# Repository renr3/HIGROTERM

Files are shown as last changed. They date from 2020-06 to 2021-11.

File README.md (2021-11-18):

# HIGROTERM
This is the official repository of the open-source HIGROTERM system for laboratory monitoring of temperature and humidity.

Any scientific publications regarding HIGROTERM will be also made available here, whether in full text or reference links.

If you find HIGROTERM useful for your scientific work, or if you have used HIGROTERM in some way, consider citing the the following references:

  1. R. Rocha Ribeiro, E. Bauer, and R. Lameiras, “HIGROTERM: An Open-Source and Low-Cost Temperature and Humidity Monitoring System for Laboratory Applications”, <em>Inventions</em>, vol. 6, no. 4, p. 84, Nov. 2021. https://doi.org/10.3390/inventions6040084 
  2. **HIGROTERM repository on GitHub**: Rocha Ribeiro, R. (2021). renr3/HIGROTERM: First release (v0.1). Zenodo. https://doi.org/10.5281/zenodo.5525381 

The HIGROTERM system is an open-source temperature and humidity system developed at the Laboratory of Material Testing at the Department of Civil and Environmental Engineering of the University of Brasília.

In order to use the source code in your hardware, please access the "Source Code" folder and access the "A000_SourceCode_HIGROTERM_EnPtVersion_v0_4_DUE_Version", in which all the source .ino files are available, as well as two C files containing icon and fonts definition. The files in the "Documentation" folder will help you to understand the source code structure and to install the necessary libraries to upload the sketch in your Arduino.

The schematics for the PCB required to build and run the current version of HIGROTERM are dhown in the "Schematics" folder. The paper “HIGROTERM: An Open-Source and Low-Cost Temperature and Humidity Monitoring System for Laboratory Applications” thoroughly explains how to build a breadboard version, the Bill of Materials and other information required to replicate the system's hardware.

The HIGROTERM source code itself is licensed under the MIT license. However, the source code makes use of external libraries developed by third parties that are licensed under a myriad of different licenses. Please, make sure you consult the Documentations folder, in which the PDF file "ABOUT THE LIBRARIES" contains links to each library, as well as their current licenses (11, June 2020), in order to check if the use you intend for the HIGROTERM system complies with all the licenses involved.

Finally, for further guidance regarding the source code and libraries, please refer to the Documentation folder, into which you will find a PDF file "ABOUT THE SOURCE CODE" with a brief explanation about the source code structure, and the libraries used by the HIGROTERM source code, as well as the links to download them and the license under which they are released, in the PDF file "ABOUT THE LIBRARIES".

Hope you enjoy the project.

Best regards,

Renan Rocha Ribeiro

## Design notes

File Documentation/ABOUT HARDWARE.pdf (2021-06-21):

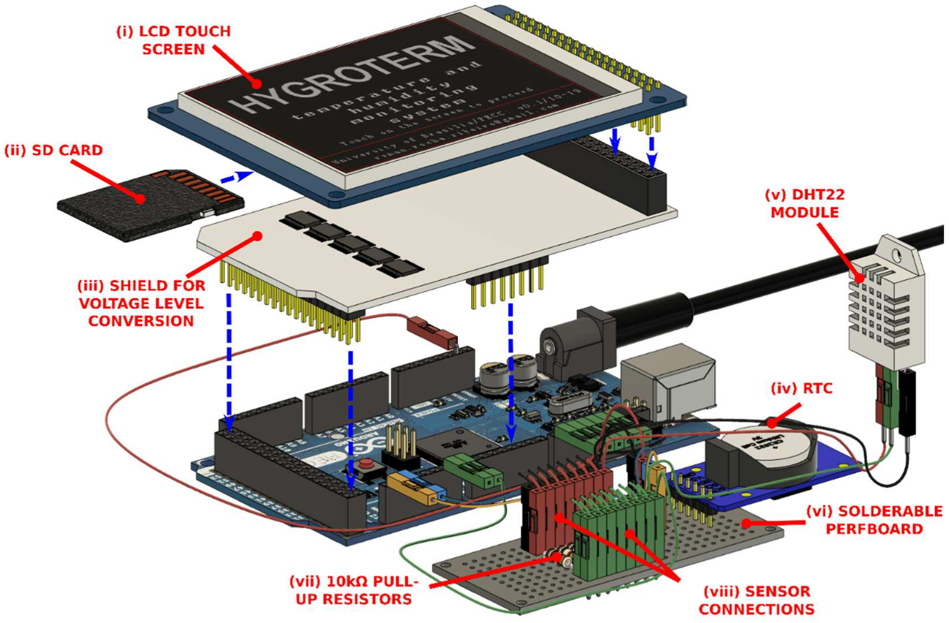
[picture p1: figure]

1

ABOUT HARDWARE USED

Renan Rocha Ribeiro

20, june of 2021

The HIGROTERM system is based upon the Arduino Mega board, DHT22 humidity and

temperature sensors, solderless breadboard and necessary cables and connectors. The full

description of the system will be part of a scientific published paper soon. In this document, a

brief explanation of the hardware necessary to build the HIGROTERM system is given.

An overall view of the system is shown in Figure 1 and how to easily assemble it in a perfboard

style.

Figure 1 Overall view of the hardware.

Figure 2 shows in more details the cable connection, without including the LCD screen and shield

for voltage level conversion, as they are directly stacked upon the Arduino Mega board. The

pinout connection shown is the same as used in the source code of the system. For better clarity,

the example only includes two units of DHT22 sensor, although the data lines for the 8 channels

are available and illustrated, although not connected to sensors.

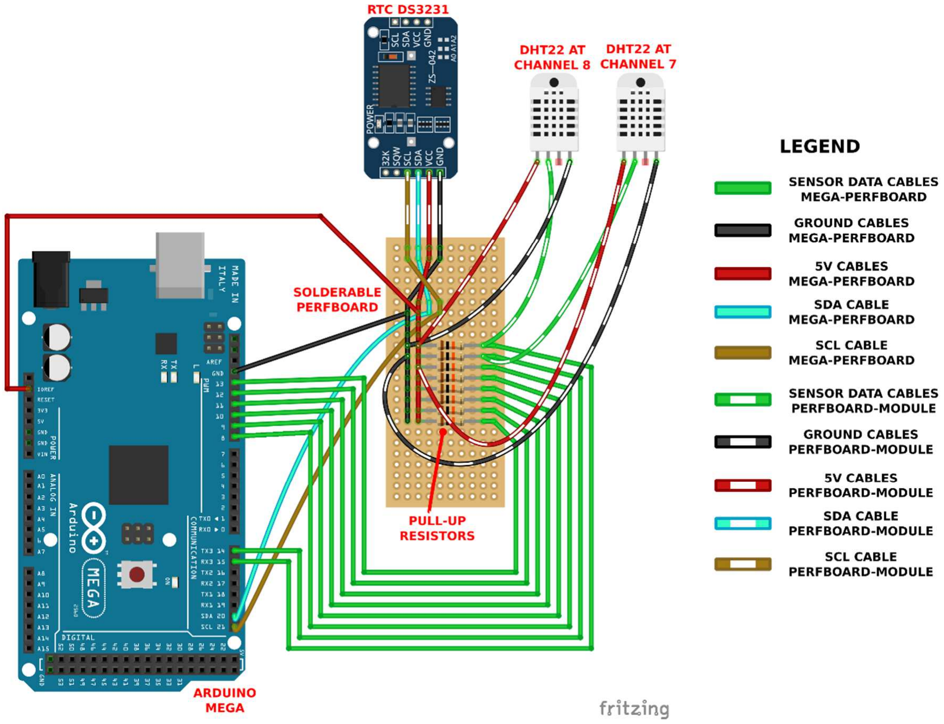
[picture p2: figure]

2

Figure 2 Cable connection using perfboard.

Figure 3 shows in more detail the cable connection using a breadboard. The shield for voltage

level conversion is shown for completeness’ sake, but its connection is to be done in a stacked

form. In Figure 3, 2EDG connectors, shown in green, are included to better reflect a suggestion

of a more reliable and flexible way to build the system and connect the sensors.

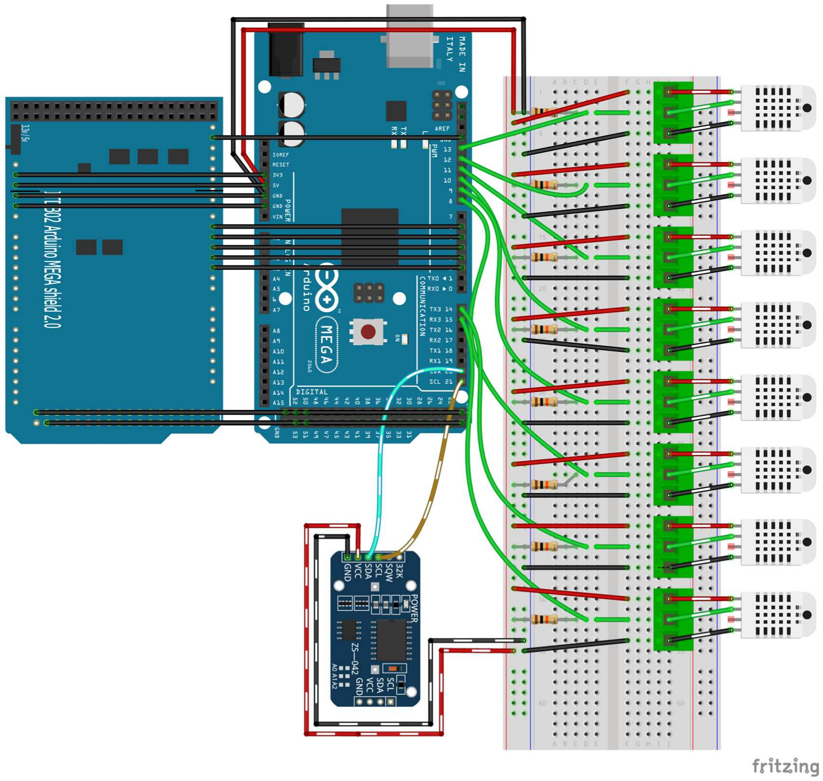
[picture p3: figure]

3

Figure 3 Cable connection using breadboard. The shield for voltage level conversion is shown with cables, but its connection should be stacked.

Figure 4 shows the circuit schematics of the system shown in Figure 3, for better tracing of the

connection routes. This same schematics is included in this repository as a GERBER file and

Fritzing native file.

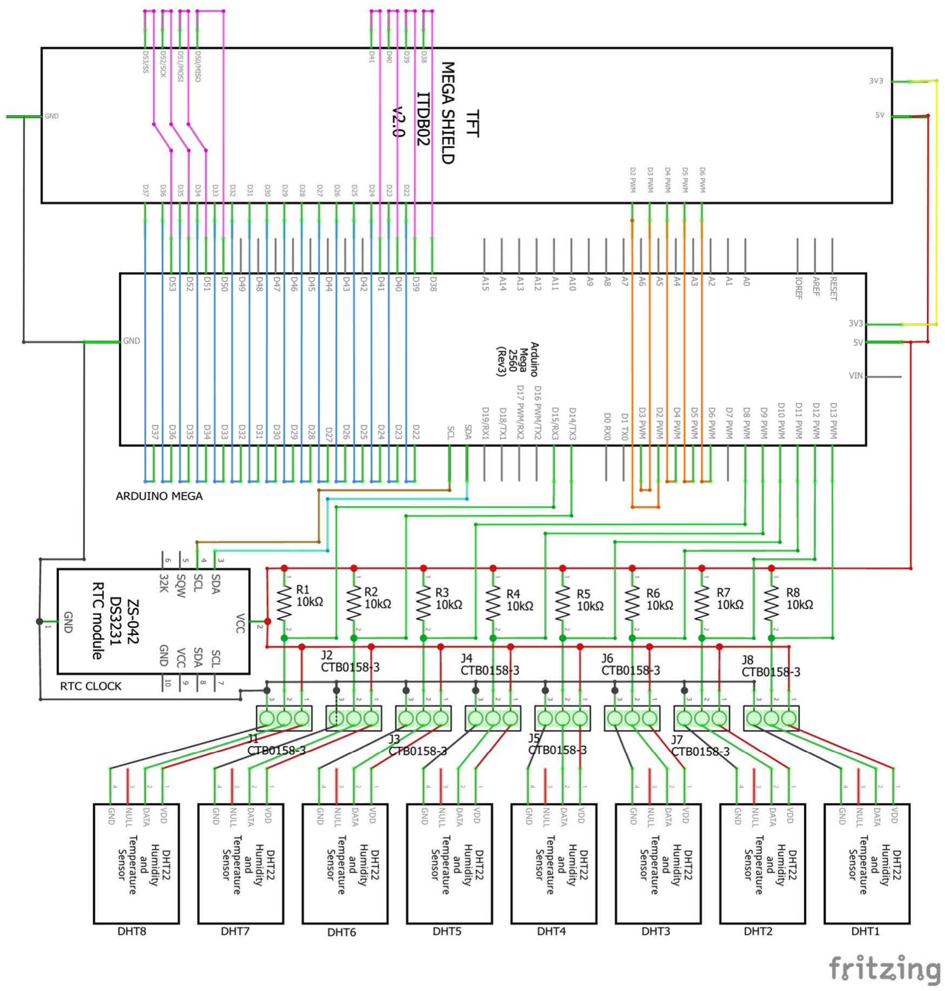
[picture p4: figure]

4

Figure 4 Schematic.

Table 1 presents the bill of materials for the system. This bill includes the 2EDG connectors to allow the unplugging the DHT22 sensors as desired, for better practicability. It also includes 4 core AWG cables that shall be used to connect the sensors to the system and a rectangular rigid plastic enclosure box for a better system aesthetic.

Component | Quantity
Arduino MEGA board (clone) | 1
3.2’’ 240X320 LCD touch screen model TFT_320QDT_9341 | 1
Voltage level conversion shirl model – TFT LCD Mega Shield V2.2 | 1
8 GB microSD card | 1
12 V power supply adapter | 1
RTC DS3231 module | 1
DHT module | 8
Solderable perfboard | 1
10 kΩ resistor | 8

5

2.54mm jumper cables (male-male) – pack with 40 units | 1
2.54mm jumper cables – male-female – pack with 40 units | 1
2.54mm female pin socket connector | 40
2EDG connector | 8
4 core AWG cable to connect sensors to system (1 meter) | 10
Rectangular rigid plastic enclosure box | 1

Table 1 Bill of materials.

6

Blank

(maybe not anymore...)

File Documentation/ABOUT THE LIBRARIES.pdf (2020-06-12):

1

## ABOUT THE LIBRARIES USED

Renan Rocha Ribeiro

11, may of 2020

The HIGROTERM source code uses 9 libraries. The table below presents them, as well as a link

in which the user can get the library and the license upon which they are currently distributed.

Library | Link | License
UTFT.h | http://www.rinkydinkelectronics.com/library.php?id=51 | CC BY-NC-SA 3.0
URTouch.h | http://www.rinkydinkelectronics.com/library.php?id=92 | CC BY-NC-SA 3.0
SPI.h | https://www.arduino.cc/en/Reference/SPI | GNU GPL
SdFat.h | https://github.com/greiman/SdFat | MIT
uRTCLib.h | https://github.com/Naguissa/uRTCLib | GNU LGPL
Wire.h | https://www.arduino.cc/en/Reference/Wire | GNU GPL
DHT.h | https://github.com/adafruit/DHT-sensor-library | MIT
avr/dtostrf.h | https://www.arduino.cc/en/Reference/UsingAVR | Modified BSD
avr/pgmspace.h | https://www.arduino.cc/en/Reference/UsingAVR | Modified BSD

In order to install an Arduino library in your IDE, the user may refer to the following link: https://www.arduino.cc/en/Guide/Libraries.

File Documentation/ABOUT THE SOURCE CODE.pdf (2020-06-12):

## TO DEVELOPERS AND CURIOUS USERS

Renan Rocha Ribeiro

11, may of 2020

### Foreword

The current source code of the HIGROTERM system is implemented using functions for

everything. This may sound odd when one considers other widespread and well-known

programming paradigms that may be more adequate to the work being done here, such as Object-

oriented programming. In fact, it was only when this project was already mature that occurred to

me that I should have implemented it using Object-oriented programming for better understand

of interested users, developers, and collaborators. The use of such old-fashion functions to

structure the system may be explained by two reasons:

- I am not fluent in Object-oriented programming;
- The HIGROTERM system was developed almost without intention, with small upgrades

ranging along a wide period of time. So, it was not planned in the beginning to be released

to the public as, maybe, a useful tool for others.

With that said, I am aware that refactoring the code to Object-oriented programming would

contribute to others understanding the logic and structure I employed, and, ultimately, to a

widespread of the system. I do not make a compromise to undertake this task, but once this code

is completely open to the public, I do hope someone gets interested in doing this.

For others only looking to use the system, or willing to make only small upgrades and

customizations, I hope the “function-ish” structure does not look so messy.

### Source code structure

The basic structure of the source code is a core that runs continuously and performs two main

tasks: (i) checks in which state the system is, i.e. which screen the user is accessing; (ii) handles

the sampling process. For those familiar with Arduino, this core is, in fact, the void loop part of

the source code.

The system currently contains 8 screens, and it mainly works from the so-called Monitoring

Table Screen. This screen is the basic screen of the system, in which the user sees sensor’s

measurements, start and stop samplings, and access other screens. It is the screen in which the

void loop runs upon.

The void loop continuously checks if buttons contained in the Monitoring Table Screen have

been pressed by the user. The Monitoring Table Screen has three buttons that allows to execute

the following tasks:

- Start a recording session;
- Stop a recording session;
- Open the Configuration Screen, that has its own buttons that may set system’s variables

or allow the user to access other screens.

Once void loop detects one of these buttons were pressed, the appropriate function is called by

the system to perform these tasks. If a recording session has been started, the void loop starts to

also handle this task by continuously checking if a new sample needs to be taken.

Once the Configuration Screen is accessed, the function used to draw it on the screen contains

a loop function executing a task very similar to void loop: continuously checks for buttons

pressed, to either alter variable’s values or to enter new screens. Once a new screen is accessed,

the function used to draw it also contains a similar loop that perform these tasks also. In this way,

the system navigates through various screens, once at a time, by calling its drawing functions.

### Source file structure

Since almost all tasks of the system are executed by functions, it was decided to use a functionality

supplied by the Arduino IDE that is dividing the source files (of the .ino extension) into various

parts. When compiling, the IDE merges these files sequentially, based on their name’s

alphanumerical ordering.

In this way, intending to ease the understanding and navigation of other users throughout the code,

the source file was divided in 37 small files, grouped with an alphanumerical codification based

on what the functions contained in those files perform. Mostly, each file contains a single

function, that lends its name to the file.

Codification | DESCRIPTION - What can you find in this series of files
A000 | Main code of the system, in which all the other functions are called
A0X | All buttons definitions, used in all screens, are declared in this file
A1X | All functions related to the Initial Screen
A2X | All functions related to the Loading Screen
A3X | All functions related to the Monitoring Table Screen
A4X | All functions related to the Configuration Screen
A5X | All functions related to the SD card
A6X | All functions related to the DHT sensors
A7X | All functions related to the Set Clock Screen
A8X | All icons bitmaps are declared here
A9X | Miscellaneous functions, with general purposes, are declared here

Blank

(maybe not anymore...)

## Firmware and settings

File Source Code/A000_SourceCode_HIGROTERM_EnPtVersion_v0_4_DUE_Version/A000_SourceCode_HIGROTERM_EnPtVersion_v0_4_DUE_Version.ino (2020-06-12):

/*  HIGROTERM SYSTEM
     Developed by Renan Ribeiro, in the Graduate program in Structures and Civil Construction
     at the University of Brasília, Brasília-DF-Brazil.
     Current version: 0.4
    ===============================
    Licensing:
    The code contained here is released under MIT license. 
    But this code do use external libraries that are licensed under different licenses. For that matter,
    a list of the other licenses is presented below:
      -CC BY-NC-SA 3.0
      -GNU GENERAL PUBLIC LICENSE
      -GNU LESSER GENERAL PUBLIC LICENSE
      -MIT LICENSE
      -Modified BSD
    The license of each library is stated after the library declaration in the code, above.
    To the best of the author's knowledge, these are the licenses involved in the current system.
    Before making any use of the HIGROTERM system, the user should check if the intended use comply with the
    restrictions predicted by each license.
    In particular, we highlight the CC BY-NC-SA 3.0, associated with the UTFT.h and URTouch.h libraries, that
    does not allow commercial use.
    ===============================
    Version 0.1:
    - Release version;
    Version 0.2:
    - Added dual language option, based on variable byte language.
    - Added setting time and damage from within the system
    Version 0.3:
    - ################  THIS VERSION IS FOR THE PAPER WRITING ONLY. IT WAS MODIFIED IN THE FUNCTION initialize_SD TO BYPASS ITS VERFICATION ################ 
    - Fixing handling invalid RTC Clock configuration (which may occurs when it is badly wired) that would print 2 digits in each house
    Version 0.4:
    - Breaking up of the source code into multiple header files
    - Total of lines (except icons and fonts): 2389
    - With icons: 3188
    ===============================
    Implementation notes:
   The page indexing, to be used to facilitate the screen update, is based on
   the variable currentPage. On the present implementation, the following table
   is followed:
    -currentPage = 0: Initial screen
    -currentPage = 1: Loading screen
    -currentPage = 2: Monitoring Table screen
    -currentPage = 3: Configuration screen
    ===============================
    TODO LIST:
    -TODO 1: In void closeFile_SD(){...} - implement conditions to deal with unsuccessful .close method. Check SdFat.h to know more about the .close method and its returns.
    -TODO 2: In void readTemp_DHT(){...} and readHum_DHT(){...) - implement a check/message to deal with the issue when a sensor can not be read after 10 tries
    -TODO 3: In void initialize_SD(){...} - Implement SD card initialization in Monitoring Table Screen. Right now, it is just performed on Loading Screen. If you disconnect the SD card, you need to run Loading Screen again by using the Configuration Screen.
    -TODO 4: Separate the icons bitmaps into an external .c file #Implemented on v0.4
    -TODO 5: Account for leap year (in: drawSetClockScreen()) 
    -TODO 6: Implement a live graphic version of MonitoringTableScreen, so the user can see the evolution of the variables during sampling
    -TODO 7: Implement !file.sync() method in the logData_SD function, so to prevent the system from losing data due to power loss
  //
    ===============================
    Ackowledgements:
    -This sketch uses the UTFT and URTouch libraries made by Henning Karlsen. You can find and download them at: www.RinkyDinkElectronics.com
    -This sketch is based on "Arduino TFT Tutorial Program" made by Dejan Nedelkovski. You can find it in: www.HowToMechatronics.com
    -This sketch uses parts of "Simple data logger example" from SdFat.h library. You can find it in  https://github.com/greiman/SdFat/archive/master.zip
*/


//=========== Importing libraries
#include <UTFT.h> //CC BY-NC-SA 3.0
#include <URTouch.h> //CC BY-NC-SA 3.0
#include <SPI.h> //GNU GENERAL PUBLIC LICENSE
#include <SdFat.h> //MIT License
#include <uRTCLib.h>//GNU LESSER GENERAL PUBLIC LICENSE
#include <Wire.h> //GNU GENERAL PUBLIC LICENSE
#include <DHT.h> //MIT License
#include <avr/dtostrf.h> //Modified BSD - Necessary so this code can be used in Arduino DUE as well, in which the dtostrf.h is not natively available
#include <avr/pgmspace.h> //Modified BSD - Necessary in order to plot bitmaps in Arduinos other than Arduino Due

//=========== DHT definitions
#define DHTPIN1 8 //Sensor 1 pin
#define DHTPIN2 9 //Sensor 2 pin   
#define DHTPIN3 10 //Sensor 3 pin   
#define DHTPIN4 11 //Sensor 4 pin  
#define DHTPIN5 12 //Sensor 5 pin   
#define DHTPIN6 13 //Sensor 6 pin  
#define DHTPIN7 14 //Sensor 7 pin   
#define DHTPIN8 15 //Sensor 8 pin
#define DHTTYPE DHT22   // DHT 22  (AM2302), AM2321
DHT dhtSensor[] = {DHT(DHTPIN1, DHTTYPE), DHT(DHTPIN2, DHTTYPE), DHT(DHTPIN3, DHTTYPE), DHT(DHTPIN4, DHTTYPE), DHT(DHTPIN5, DHTTYPE), DHT(DHTPIN6, DHTTYPE), DHT(DHTPIN7, DHTTYPE), DHT(DHTPIN8, DHTTYPE)};
float t1[8] = {0.0, 0.0, 0.0, 0.0, 0.0, 0.0, 0.0, 0.0}; //Variables to store current temperature measured. This is used to receive sensor data and display values in the table.
float h1[8] = {0.0, 0.0, 0.0, 0.0, 0.0, 0.0, 0.0, 0.0}; //Variables to store current temperature measured. This is used to  receive sensor data and display values in the table.
byte selectedChannels[8] = {0, 0, 0, 0, 0, 0, 0, 0}; //Sensor chanels. A "0" indicates channel is not selected/connected/used by the user. A 1 indicates the channel is selected/connected/used by the user

//=========== Display definitions
UTFT    myGLCD(ILI9341_16, 38, 39, 40, 41);
URTouch  myTouch( 6, 5, 4, 3, 2); 
byte currentPage; //Will store which page we are currently showing in the screen
uint8_t recording = 0; //Will indicate whether we are storing/recording sensor data in the SD card
int x, y; //Variables for touch screen coordinates when pressed
byte language = 0; //Variable to indicate display language: 0 - English; 1 -  Portuguese; ...
byte configureFlag = 0; //Flag that indicates what to do after visiting the Configuration Screen

//=========== Import external fonts and bitmaps
//Fonts
extern uint8_t SmallFont[]; //Importing font.
extern uint8_t BigFont[]; //Importing font.
extern uint8_t SevenSegNumFont[]; //Importing font.
extern uint8_t GroteskBold32x64[]; //Importing font.
extern uint8_t Various_Symbols_32x32[]; //Importing font.
//Bitmaps
extern uint16_t img_home2_png[] ;
extern uint16_t img_brazilFlag_png[];
extern uint16_t img_ukFlag_png[];
extern uint16_t img_clock_png[];
extern uint16_t img_home2_Inactive_png[];
extern uint16_t img_turnOff_png[];
extern uint16_t img_turnOff_Inactive_png[];
extern uint16_t img_clock_Inactive_png[];
extern uint16_t img_saveandreturn_png[];
extern uint16_t img_return_png[];
extern uint16_t img_saveandreturn_Inactive_png[];
extern uint16_t img_return_Inactive_png[];

//=========== Sampling frequency definitions
unsigned long time1 = 0; unsigned long time2 = 0; unsigned long timeUpdate = 0; //Variables to set the sampling frequency
unsigned long fs = 150000; //CHECK THIS COMMENT: Time between consecutive measurements. Default sampling frequency is 2.5 minutes. It is not sampling frequency per se, but the time elapsed between two consecutive reads, in milliseconds

//=========== Clock definitions
uRTCLib rtc(0x68); //Instancing RTC clock object
//Variables to store time and data and each decimal place (tens and units)
byte hours = 0; byte minutes = 0; byte seconds = 0; byte days = 0; byte months = 0; byte years = 0;
byte hoursTens = 0; byte hoursUnits = 0; byte minutesTens = 0; byte minutesUnits = 0; byte secondsTens = 0; byte secondsUnits = 0;
byte daysTens = 0; byte daysUnits = 0; byte monthsTens = 0; byte monthsUnits = 0; byte yearsTens = 0; byte yearsUnits = 0;

//=========== SD card definitions
#define SD_CHIP_SELECT  53  // SD chip select pin
SdFat sd; //Instancing SD object
SdFile file; //Creating log file
#define FILE_BASE_NAME "Data" // Log file base name, i.e. "Data" will be the prefix of all data files, e.g. "Data01.csv", "Data02.csv", etc.  Must be no more than six characters
const uint8_t BASE_NAME_SIZE = sizeof(FILE_BASE_NAME) - 1; //This is to assure a size less than six characters
char fileName[13] = FILE_BASE_NAME "00.csv"; //Building the first log file name
byte openFile_SDStatus = 0; //Assumes 0 or 1 if file could or could not be opened, respectively. To receive the return from openFile_SD() function

//=========== Log table prompt at Monitoring Table Screen
byte dataLogConsole_MonitoringTableScreen_State = 0; //Shows how many lines have been fed to Data Log Console, on the Monitoring Table Screen, to allow automatic scrolling from past lines to free display space for new text
char dataLogTable1[27] = "01:                      "; //Message 1 in the data log screen (Monitoring Table)
char dataLogTable2[27] = "02:                      "; //Message 2 in the data log screen (Monitoring Table)
char dataLogTable3[27] = "03:                      "; //Message 3s in the data log screen (Monitoring Table)

//=========== Definitions of button areas at touchscreen
//Record and Stop button at Monitoring Table Screen
const int recordStopBut_MonitTabScren_Xmin = 7;
const int recordStopBut_MonitTabScren_Xmax = 45;
const int recordStopBut_MonitTabScren_Ymin = 13;
const int recordStopBut_MonitTabScren_Ymax = 51;

//Configuration button at Monitoring Table Screen
const int configBut_MonitTabScren_Xmin = 274;
const int configBut_MonitTabScren_Xmax = 312;
const int configBut_MonitTabScren_Ymin = 13;
const int configBut_MonitTabScren_Ymax = 51;

//OK button at Loading Screen
const int OKBut_LoadingScreen_Xmin = 239;
const int OKBut_LoadingScreen_Xmax = 319;
const int OKBut_LoadingScreen_Ymin = 159;
const int OKBut_LoadingScreen_Ymax = 239;

//"S1","S2","S3","S4","S5","S6","S7","S8" buttons at Loading Screen
const int sensorSelectionBut_LoadingScreen_Xwidth = 40;
const int sensorSelectionBut_LoadingScreen_Ymin = 95;
const int sensorSelectionBut_LoadingScreen_Ymax = 140;

//Home Screen button at Configuration Screen
const int HomeScreenBut_ConfigScreen_Xmin=135;
const int HomeScreenBut_ConfigScreen_Xmax=183;
const int HomeScreenBut_ConfigScreen_Ymin=116;
const int HomeScreenBut_ConfigScreen_Ymax=164;

//Turn Off button at Configuration Screen
const int TurnOffBut_ConfigScreen_Xmin=237;
const int TurnOffBut_ConfigScreen_Xmax=285;
const int TurnOffBut_ConfigScreen_Ymin=116;
const int TurnOffBut_ConfigScreen_Ymax=164;

//Reload button at Configuration Screen
const int ReloadBut_ConfigScreen_Xmin=33;
const int ReloadBut_ConfigScreen_Xmax=81;
const int ReloadBut_ConfigScreen_Ymin=116;
const int ReloadBut_ConfigScreen_Ymax=164;

//Set Clock/Date button at Configuration Screen
const int SetClockDateBut_ConfigScreen_Xmin=89;
const int SetClockDateBut_ConfigScreen_Xmax=119;
const int SetClockDateBut_ConfigScreen_Ymin=197;
const int SetClockDateBut_ConfigScreen_Ymax=227;

//Set Language button at Configuration Screen
const int SetLanguageBut_ConfigScreen_Xmin=182;
const int SetLanguageBut_ConfigScreen_Xmax=234;
const int SetLanguageBut_ConfigScreen_Ymin=194;
const int SetLanguageBut_ConfigScreen_Ymax=230;

void setup() {
  Serial.begin(115200); //At use we don't really need Serial. We can comment out this line.
  Wire.begin(); //Start wire to allow peripheral communications
  myGLCD.InitLCD(); //Start LCD
  myGLCD.clrScr(); //Clear LCD screen
  myTouch.InitTouch(); //Start touchscreen
  myTouch.setPrecision(PREC_HI); //Set touchscreen precision. Check URTouch documentation for further details about .setPrecision method.
  currentPage = 0; // Indicates that we are at Initial Screen,
  drawInitialScreen();  // Draws the Initial Screen
  drawLoadingScreen();  // Draws the Loading Screen
}

void loop() {
  if (currentPage != 2) { //The code will only get here if we came from another screen that is not the Monitoring Table Screen. Therefore, we need to initialize it. This is what this if-clause does
    drawMonitoringTableScreen(); //Draw the Monitoring Table Screen
    updateSensorData_DHT(); //It asks each sensor for current data, and update t1 and h1 variables.
    updateSensorDataTable_MonitoringTableScreen(); //Updates sensor table with the latest sensor values, taken from the last updateSensorData_DHT function
    timeUpdate = millis(); //Initializes this variable. The DataTable will only update again when [current millis()]-timeUpdate > fs, i.e. a time greater than fs, in miliseconds, has elapsed since the last table update
  } else { //Indicates we are at the Monitoring Table Screen
    if (myTouch.dataAvailable()) { //Read touch screen data, if available, to know if any command has been sent by the user
      myTouch.read(); //Method to read data from touch screen
      x = myTouch.getX(); // X coordinate where the screen has been pressed
      y = myTouch.getY(); // Y coordinates where the screen has been pressed
    }
    //If we pressed the Config Button, that will only work if recoring is off. (Move above recordStopBut check for better clarity)
    if ((x >= configBut_MonitTabScren_Xmin) && (x <= configBut_MonitTabScren_Xmax) && (y >= configBut_MonitTabScren_Ymin) && (y <= configBut_MonitTabScren_Ymax) && recording == 0) {//If we pressed the Configuration button
      drawConfigButton_Inactive_MonitoringTableScreen(); //Makes the Configuration button Inactive, so the user can't change configuration while logging, since such configuration will affect the logging
      delay(250); //Delay so one touch is not seen as multiple touches
      configureFlag = drawConfigurationScreen(); //Draw the Configuration Screen and store its return on "configureFlag" variable, which will indicate what to do after the user interact with the Configuration Screen
      if (configureFlag == 1) {//The Reload Connections button was pressed
        drawLoadingScreen();  // Draws the Loading Screen
      } else if (configureFlag == 2) {//The Home button was pressed
        drawMonitoringTableScreen(); //Draws the Monitoring Table Screen
      } else if (configureFlag == 3) {//The Turn Off button was pressed
        drawTurnOffScreen(); //It will just draw a black screen written: "You can turn off the device now"
        while (1); //System is going to be turned off. Just be here forever.
      } else if (configureFlag == 4) {//The Set Clock/Date button was pressed
        //drawSetClockScreen(); //It will draw the Set Clock/Date Screen
      }
    }
    if ((x >= recordStopBut_MonitTabScren_Xmin) && (x <= recordStopBut_MonitTabScren_Xmax) && (y >= recordStopBut_MonitTabScren_Ymin) && (y <= recordStopBut_MonitTabScren_Ymax) && recording == 0) {// If we pressed the Record Button
      drawStopButton_MonitoringTableScreen(); //Substitutes the Record button for the Stop button, that will allow stopping the data logging
      drawConfigButton_Inactive_MonitoringTableScreen(); //Makes the Configuration button Inactive, so the user can't change configuration while logging, since such configuration will affect the logging
      delay(250); //Delay so one touch is not seen as multiple touches
      recording = 1; //Updates the "recording" variable, indicating that the system is currently logging data
      resetTouch(); //Reset x and y variables so they can receive new input values
      openFile_SDStatus = openFile_SD(); //Check if file could be opened. Return 0 if file was successfully opened, or 1 if the file could not be opened/created
      if (openFile_SDStatus == 1) { //If the file could not be opened, execute these instructions to deal with the fact that logging could not be started
        recording = 0; //File could not be opened, do not let sampling proceed. A error message will be shown in the Data Log Console, in the appropriate field accordingly to the current screen
        drawRecordButton_MonitoringTableScreen(); //Draw record button again, so the user can try to start logging again after solving the issue with the SD card
      } else {//If the file could be opened, then execute this instruction...
        time1 = millis(); //Update "time1" variable. This variable will be used to know when the next data reading/logging will be done:
        timeUpdate = time1; //If we are in a recording session, we want the Monitoring Table Screen to be updated at the same instant the SD card is logged with new data.
        //the sensor data will only be read and stored again when [current millis()]- time1 > fs, i.e. a time greater than fs, in miliseconds, has elapsed since the last sensor reading/logging
      }
    }
    if ((x >= recordStopBut_MonitTabScren_Xmin) && (x <= recordStopBut_MonitTabScren_Xmax) && (y >= recordStopBut_MonitTabScren_Ymin) && (y <= recordStopBut_MonitTabScren_Ymax) && recording == 1) {//If we pressed the Stop Button
      recording = 0; //Updates the "recording" variable, indicating that the system is not logging data
      drawRecordButton_MonitoringTableScreen(); //Substitutes the Stop button by the Record button
      drawConfigButton_MonitoringTableScreen(); //Draws the Configuration button again, allowing the user to access the Configuration Screen since the logging has stoppped
      delay(250); //Delay so one touch is not seen as multiple touches
      resetTouch(); //Reset x and y variables so they can receive new input values
      closeFile_SD (); //Close the data log file
      findFileName_SD(); //Find the next available file name, or deal with the fact that the file could not be named.
    }


    time2 = millis(); //Store current time on "time2" variable
    if (recording == 1) {//To be performed if the system is under recording (recording==1)
      if (time2 - time1 > fs) {//If the difference between the current time, stored in "time2", and the time when the data was last read/logged, stored in "time1", is higher than "fs", the time between measurements,
        //then perform a data read/log
        logData_SD(); //Logs sensor data
        time1 = millis(); //Updates the "time1" variable to store the time when the system last read/logged data.
      }
    }
    if (time2 - timeUpdate > fs) { //If the difference between the current time, stored in "time2", and the time when the Monitoring Table was last updated, stored in "timeUpdate", is higher than "fs", the time between measurements,
      //then update the Monitoring Table
      updateSensorData_DHT(); //Read sensor data, updating variables t1 and h1
      updateSensorDataTable_MonitoringTableScreen (); //Updates the Monitoring Table, writing the current values of t1 and h1
      timeUpdate = millis(); //Updates the "timeUpdate" variable to store the time when the system last updated the Monitoring Table
    }
  }
}

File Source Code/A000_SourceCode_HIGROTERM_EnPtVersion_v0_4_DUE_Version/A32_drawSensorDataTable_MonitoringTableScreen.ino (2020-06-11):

/*
   This function draws the Sensor Data Table outline at the Monitoring Table Screen

   The table is to be represented as: Sensor|Temperature|RH || Sensor|Temperature|RH,
   with a total of four rows on each side of the table.
   This allows representing 8 sensor datas.

   The rows associated with connected sensors receive a red coloured background.
   The rows associa ted with non-connected sensors receive a grey coloured background.
*/


void drawSensorDataTable_MonitoringTableScreen () {

  //Declaring the vectors that will hold the colors of each row in the Sensor Data Table
  //The colors are stored in RGB values
  //The rows are divided in right hand side and left hand side, with each side having 4 rows.
  uint8_t rowColors_LeftHandSide[4][3];
  uint8_t rowColors_RightHandSide[4][3];

  //Initiate row colors vector.
  //Check which rows are associated to sensors that are not connected, applying the grey color (160,160,160)
  //and which rows are associated to sensors that are connected, applying the red color (255,0,0)
  for (byte ii = 0; ii < 4; ii++) {
    //Check the left hand side rows
    if (selectedChannels[ii] == 0) {
      rowColors_LeftHandSide[ii][0] = 160;
      rowColors_LeftHandSide[ii][1] = 160;
      rowColors_LeftHandSide[ii][2] = 160;
    } else {
      rowColors_LeftHandSide[ii][0] = 255;
      rowColors_LeftHandSide[ii][1] = 0;
      rowColors_LeftHandSide[ii][2] = 0;
    }
    //Check the right hand side rows
    if (selectedChannels[ii + 4] == 0) {
      rowColors_RightHandSide[ii][0] = 160;
      rowColors_RightHandSide[ii][1] = 160;
      rowColors_RightHandSide[ii][2] = 160;
    } else {
      rowColors_RightHandSide[ii][0] = 255;
      rowColors_RightHandSide[ii][1] = 0;
      rowColors_RightHandSide[ii][2] = 0;
    }
  }

  //Draw Sensor data boxes - First column for sensor labels
  // Graphical variables
  uint8_t xIdent = 5;
  uint8_t yHeader = 80;
  uint8_t ySpacing = 10;
  uint8_t xSpacing = 5;
  uint8_t boxHeight = 30;
  uint8_t boxWidth = 40;
  uint8_t boxExtraWidth = 9;
  //The cells_Xparameter is a value used to define the X coordinate of the rightmost vertices of the Sensor Data Table cells.
  //Depending on the column being draw, this value is multiplied by a proper parameter to position the column's cell on the screen.
  uint8_t cells_Xparameter = boxWidth + xSpacing + boxExtraWidth;
  //The cells_Yparameter is a value used to define the Y coordinate of the rightmost vertices of the Sensor Data Table cells.
  //Depending on the row being draw, this value is multiplied by a proper parameter to position the column's cell on the screen.
  uint8_t cells_Yparameter = boxHeight + ySpacing;

  char sensorLabel[3];
  uint8_t columnNumber = 0;
  uint8_t rowColors_Temporary[4][3]; //Temporary colour vector, to hold the present colour to be used in the cell being draw

  //Prints the first column, Sensor, of both left and right hand sides
  for (uint8_t columnIterator = 0; columnIterator < 2; columnIterator++) {
    //The columnNumber is a helpful parameter that will perform the necessary offset between the first Sensor column to the second
    //The first Sensor column is the first column of the Sensor Data Table, so it starts after a proper ident from the left-most side of the screen
    //The second Sensor column, however, is the 4 column in the Sensor Data Table, and its positioning must take into account the presence of the other columns.
    //The variable columnNumber takes this fact into account.
    //v0.4 noteL: Its logic is a legacy from early implementations, when each column had its own block of code, i.e. there were no for loops as implemented on v0.4.
    //            In that implementation, the first Sensor column was the Sensor Data Table column #1 and the second Sensor column was column #4.
    //In this Switch we also choose the appropriate color vector, depending on which sensor column (left or right hand side) we are drawing, and copy it to rowColors_Temporary
    switch (columnIterator) {
      case 0:
        columnNumber = 1;
        memcpy(rowColors_Temporary, rowColors_LeftHandSide, sizeof(rowColors_LeftHandSide[0]) * 4); //the memcpy function serves to copy an entire array into another
        break;
      case 1:
        columnNumber = 4;
        memcpy(rowColors_Temporary, rowColors_RightHandSide, sizeof(rowColors_RightHandSide[0]) * 4); //the memcpy function serves to copy an entire array into another
        break;
    }

    //Prints the column header
    myGLCD.setFont(SmallFont);
    myGLCD.setBackColor(0, 0, 0);
    myGLCD.setColor(255, 255, 255);
    myGLCD.print(F("Sens"), xIdent + (columnNumber - 1) * (boxWidth + xSpacing + boxExtraWidth) + 6, yHeader - 20);

    //Draws the cells
    for (uint8_t count = 0; count < 4; count++) {
      sprintf (sensorLabel, "S%d", count + 1 + 4 * (columnIterator)); //Gets the correct sensor numbering based on the column being ploted: sumns 4 in all cells from the right hand side column.
      myGLCD.setFont(BigFont);
      myGLCD.setColor(rowColors_Temporary[count][0], rowColors_Temporary[count][1], rowColors_Temporary[count][2]); // Sets color of the given line
      myGLCD.fillRect (xIdent + (columnNumber - 1)*cells_Xparameter, yHeader + count * cells_Yparameter, xIdent + boxWidth + (columnNumber - 1) * (cells_Xparameter), yHeader + boxHeight + count * cells_Yparameter); // Draws filled rectangle
      myGLCD.setBackColor(rowColors_Temporary[count][0], rowColors_Temporary[count][1], rowColors_Temporary[count][2]); // Sets color of the given line
      myGLCD.setColor(255, 255, 255);
      myGLCD.print(sensorLabel, xIdent + (columnNumber - 1)*cells_Xparameter + 5, yHeader + 7 + cells_Yparameter * count);
    }
  }

  char columnTitle[8];
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

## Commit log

2021-06-21 Update hardware notes
    Add hardware notes about how to mount the HIGROTERM hardware. Include images of schematics and mention the GERBER file.
2021-06-21 Gerber files
    Gerber files for easy mounting of the HIGROTERM v0.1/10-19 hardware.
    [20210620-PCB_V0.1_PCB-10-19_contour.gm1, 20210620-PCB_V0.1_PCB-10-19_copperBottom.gbl, 20210620-PCB_V0.1_PCB-10-19_copperTop.gtl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]
